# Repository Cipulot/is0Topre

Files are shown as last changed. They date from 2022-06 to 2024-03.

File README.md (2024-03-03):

# is0Topre

## Introduction

Topre version of the iconic is0 board.

This project is a continuation of my development of open source EC boards.

Below is the KLE of the supported layout:

is0Topre KLE

## Technical information

- Layout size: ISO enter
- Compatible switches: EC switches (Topre and NIZ)
- Microcontroller: Atmega32u4
- Connector: USB Type C
- Firmware compatibility: QMK (with VIA/VIAL support)
- Protection hardware:
  - Fused
  - ESD protection

**Addition: an empty spot for a 3.5x3.5mm SK series LED has been added to the back of the PCB, in case you want to manually add a bit of lighting.

## Renders and Prototypes

### is0Topre PCB

#### Render

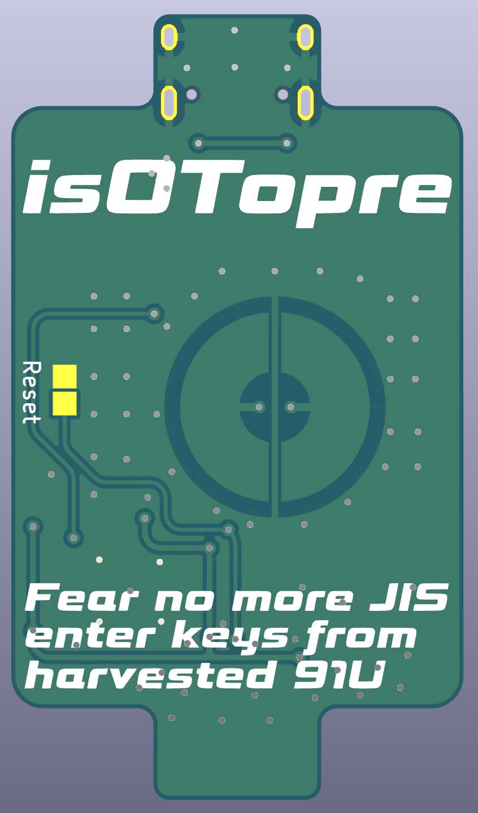
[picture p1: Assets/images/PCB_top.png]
is0Topre PCB Top Render


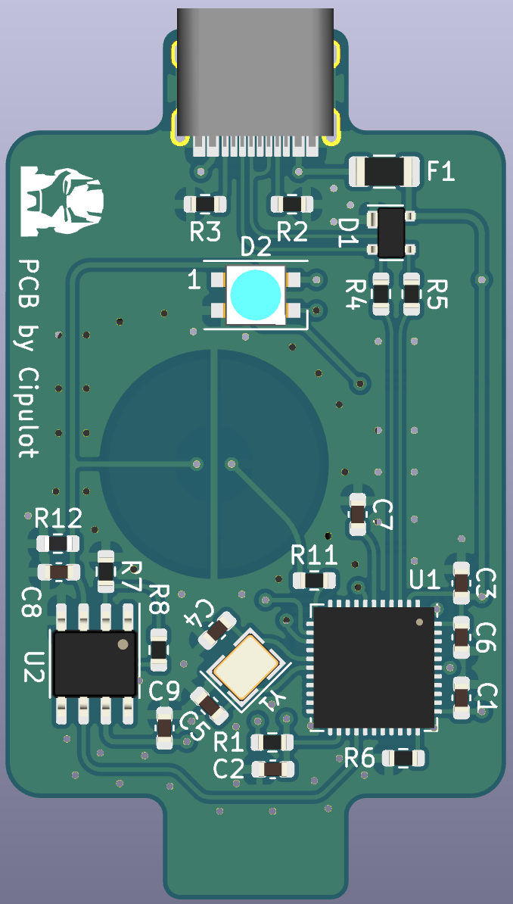
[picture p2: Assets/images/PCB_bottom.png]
is0Topre PCB Bottom Render


### Plate

#### Render

Topre housing compatible plate:

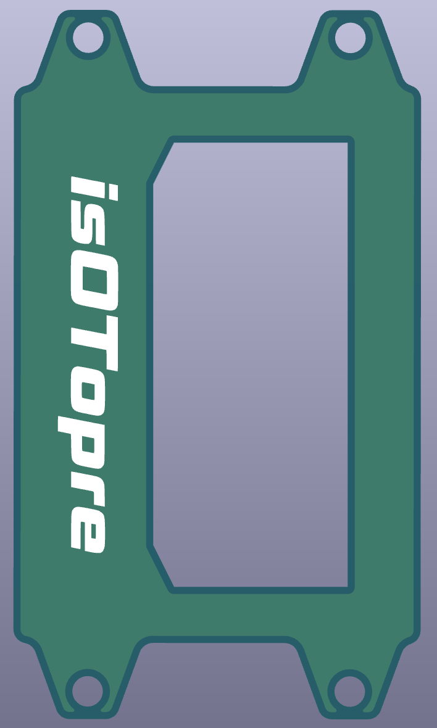
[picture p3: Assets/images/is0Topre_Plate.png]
is0Topre Plate Render


MX plate mounted stabilizer compatible plate:

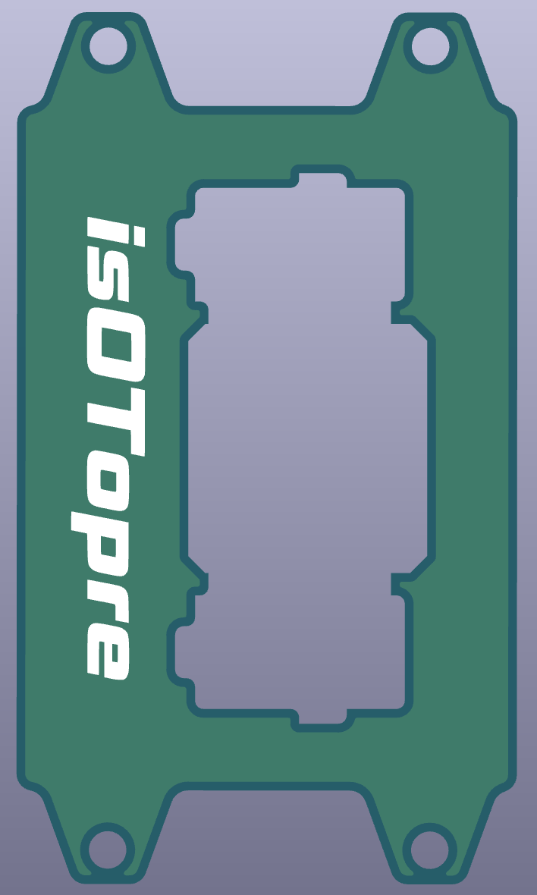
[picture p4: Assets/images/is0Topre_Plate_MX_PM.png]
is0Topre Plate MX Render


#### Prototype

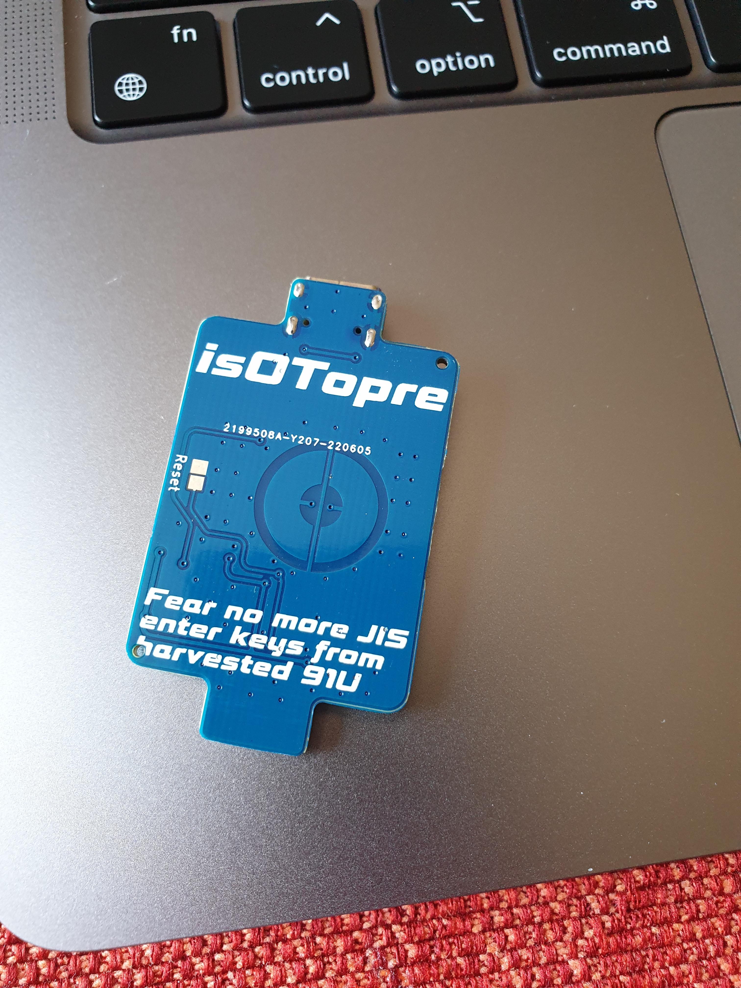
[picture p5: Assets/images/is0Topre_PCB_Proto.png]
is0Topre Proto


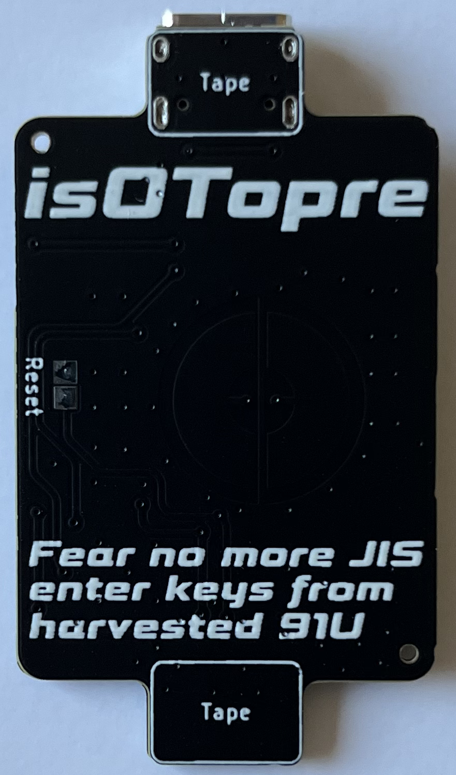
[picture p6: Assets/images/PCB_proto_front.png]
is0Topre Proto Front


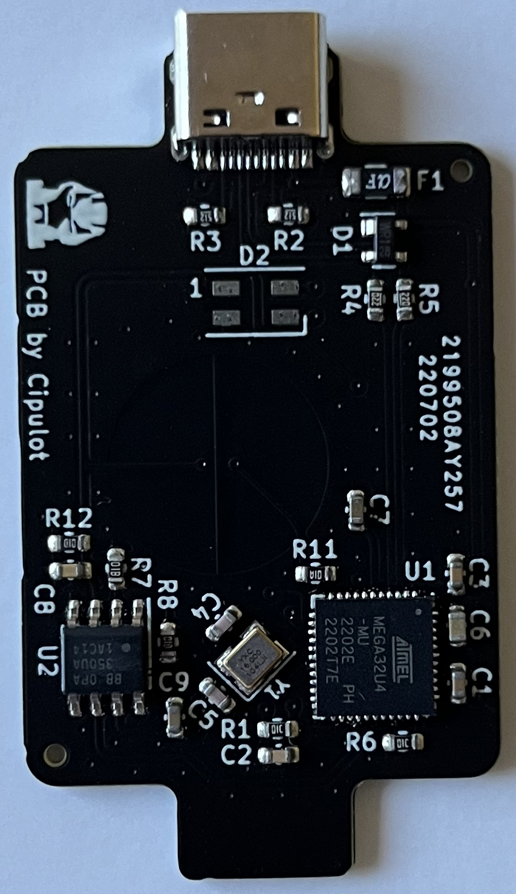
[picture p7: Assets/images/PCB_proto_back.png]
is0Topre Proto Back


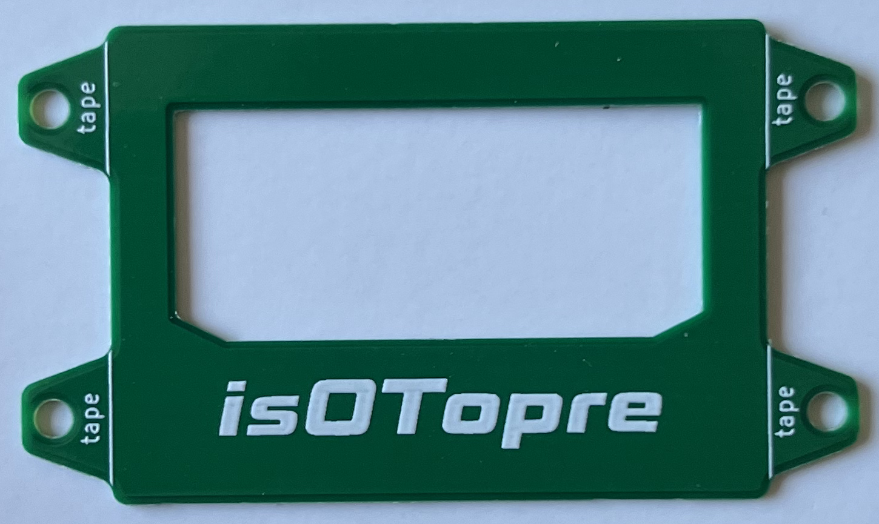
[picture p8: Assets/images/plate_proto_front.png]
is0Topre Plate Front


## WIP

Atmel MCU based firmware is validated, you can find the precompiled `.hex` (Vial compatible) and `.json` file for VIA in the firmware folder.

STM32 based MCU version is in development.

## Compatibility with is0 case

Given the difference in height and mounting system some modifications are needed.

At the time of ordering the PCBs be sure to use the following specs:

- 1.2mm thickness for the main PCB
- 0.6mm for the plates

In order to have the correct fit place in the marked spots adhesive tape, specifically:

- 2pcs, 0.4mm thick on the main PCB
- 4pcs, 0.1mm thick on the plates

These will ensure that all the tollerances are met and a secure fit is achieved.

## License

<br />This work is licensed under a <a rel="license" href="http://creativecommons.org/licenses/by-nc-sa/4.0/">Creative Commons Attribution-NonCommercial-ShareAlike 4.0 International License</a>.

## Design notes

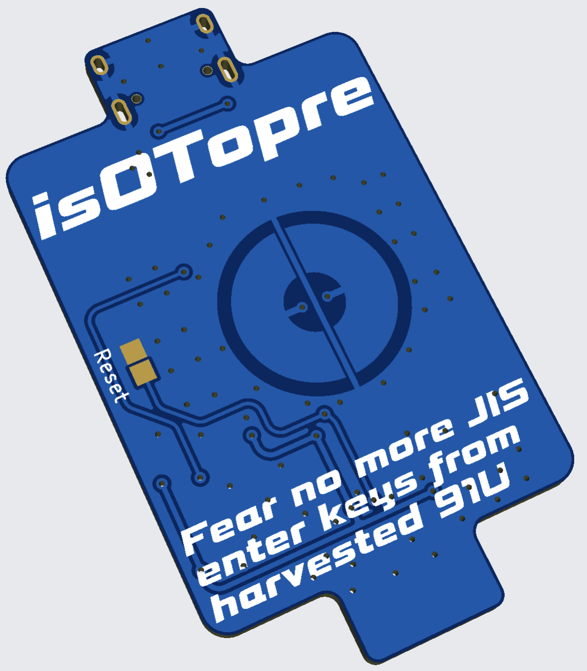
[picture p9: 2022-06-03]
Assets/images/Showcase_image.png

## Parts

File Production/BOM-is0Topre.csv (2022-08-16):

Comment | Designator | Footprint | LCSC
HRO-TYPE-C-31-M-12 | USB1 | HRO-TYPE-C-31-M-12-Assembly | C165948
1u | C7 | C_0603_1608Metric | C15849
PRTR5V0U2X | D1 | SOT-143 | C2827688
220p | C8 | C_0603_1608Metric | C1603
100k | R8,R12 | R_0603_1608Metric | C25803
10k | R6,R1 | R_0603_1608Metric | C25804
10u | C6 | C_0603_1608Metric | C96446
0.1u | C1,C9,C3,C2 | C_0603_1608Metric | C14663
22p | C5,C4 | C_0603_1608Metric | C1653
16MHz | Y1 | Crystal_SMD_3225-4pin_3.2x2.5mm | C13738
5.1k | R2,R3 | R_0603_1608Metric | C23186
22 | R5,R4 | R_0603_1608Metric | C23345
1k | R7 | R_0603_1608Metric | C21190
500mA | F1 | Fuse_1206_3216Metric | C70076
OPA350 | U2 | SOIC-8_3.9x4.9mm_P1.27mm | C13388
ATmega32U4-M | U1 | QFN-44-1EP_7x7mm_P0.5mm_EP5.2x5.2mm | C112161
100 | R11 | R_0603_1608Metric | C22775

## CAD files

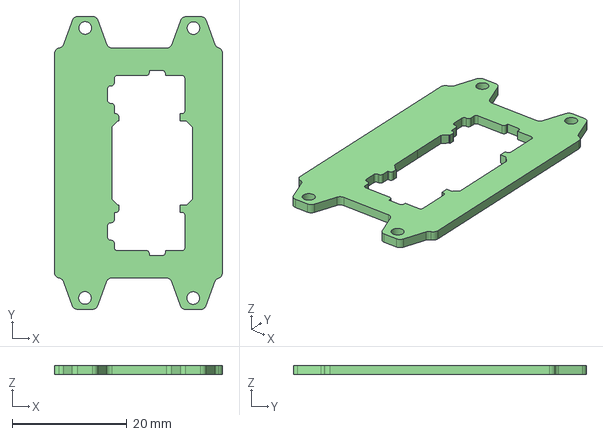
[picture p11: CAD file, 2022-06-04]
Assets/dev/is0Topre_Plate_MX_PM.STEP
29.3 x 51.1 x 1.60 mm

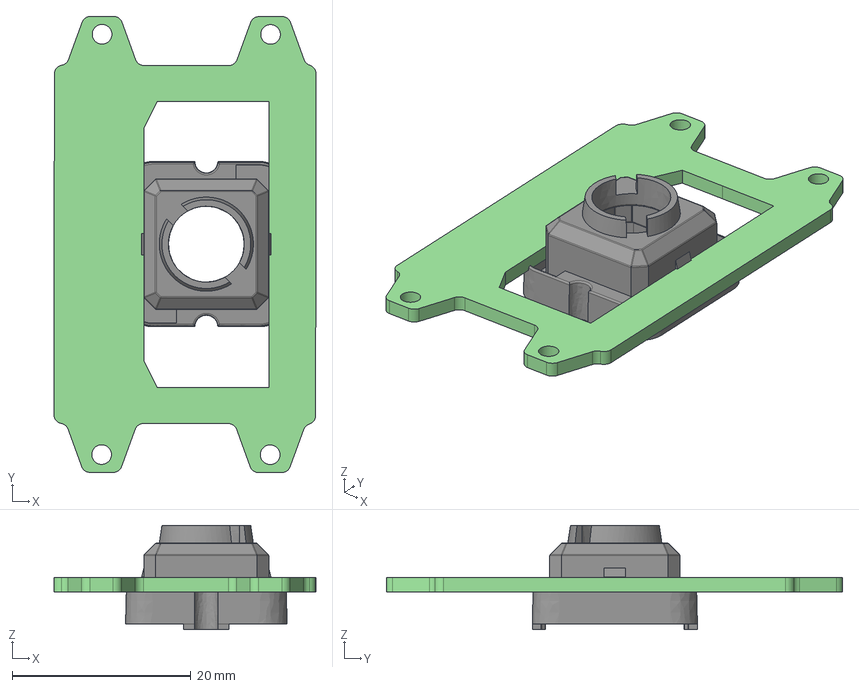
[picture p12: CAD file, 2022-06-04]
Assets/dev/is0Topre_Plate.STEP
29.3 x 51.1 x 11.7 mm
is0Topre_Plate PCB

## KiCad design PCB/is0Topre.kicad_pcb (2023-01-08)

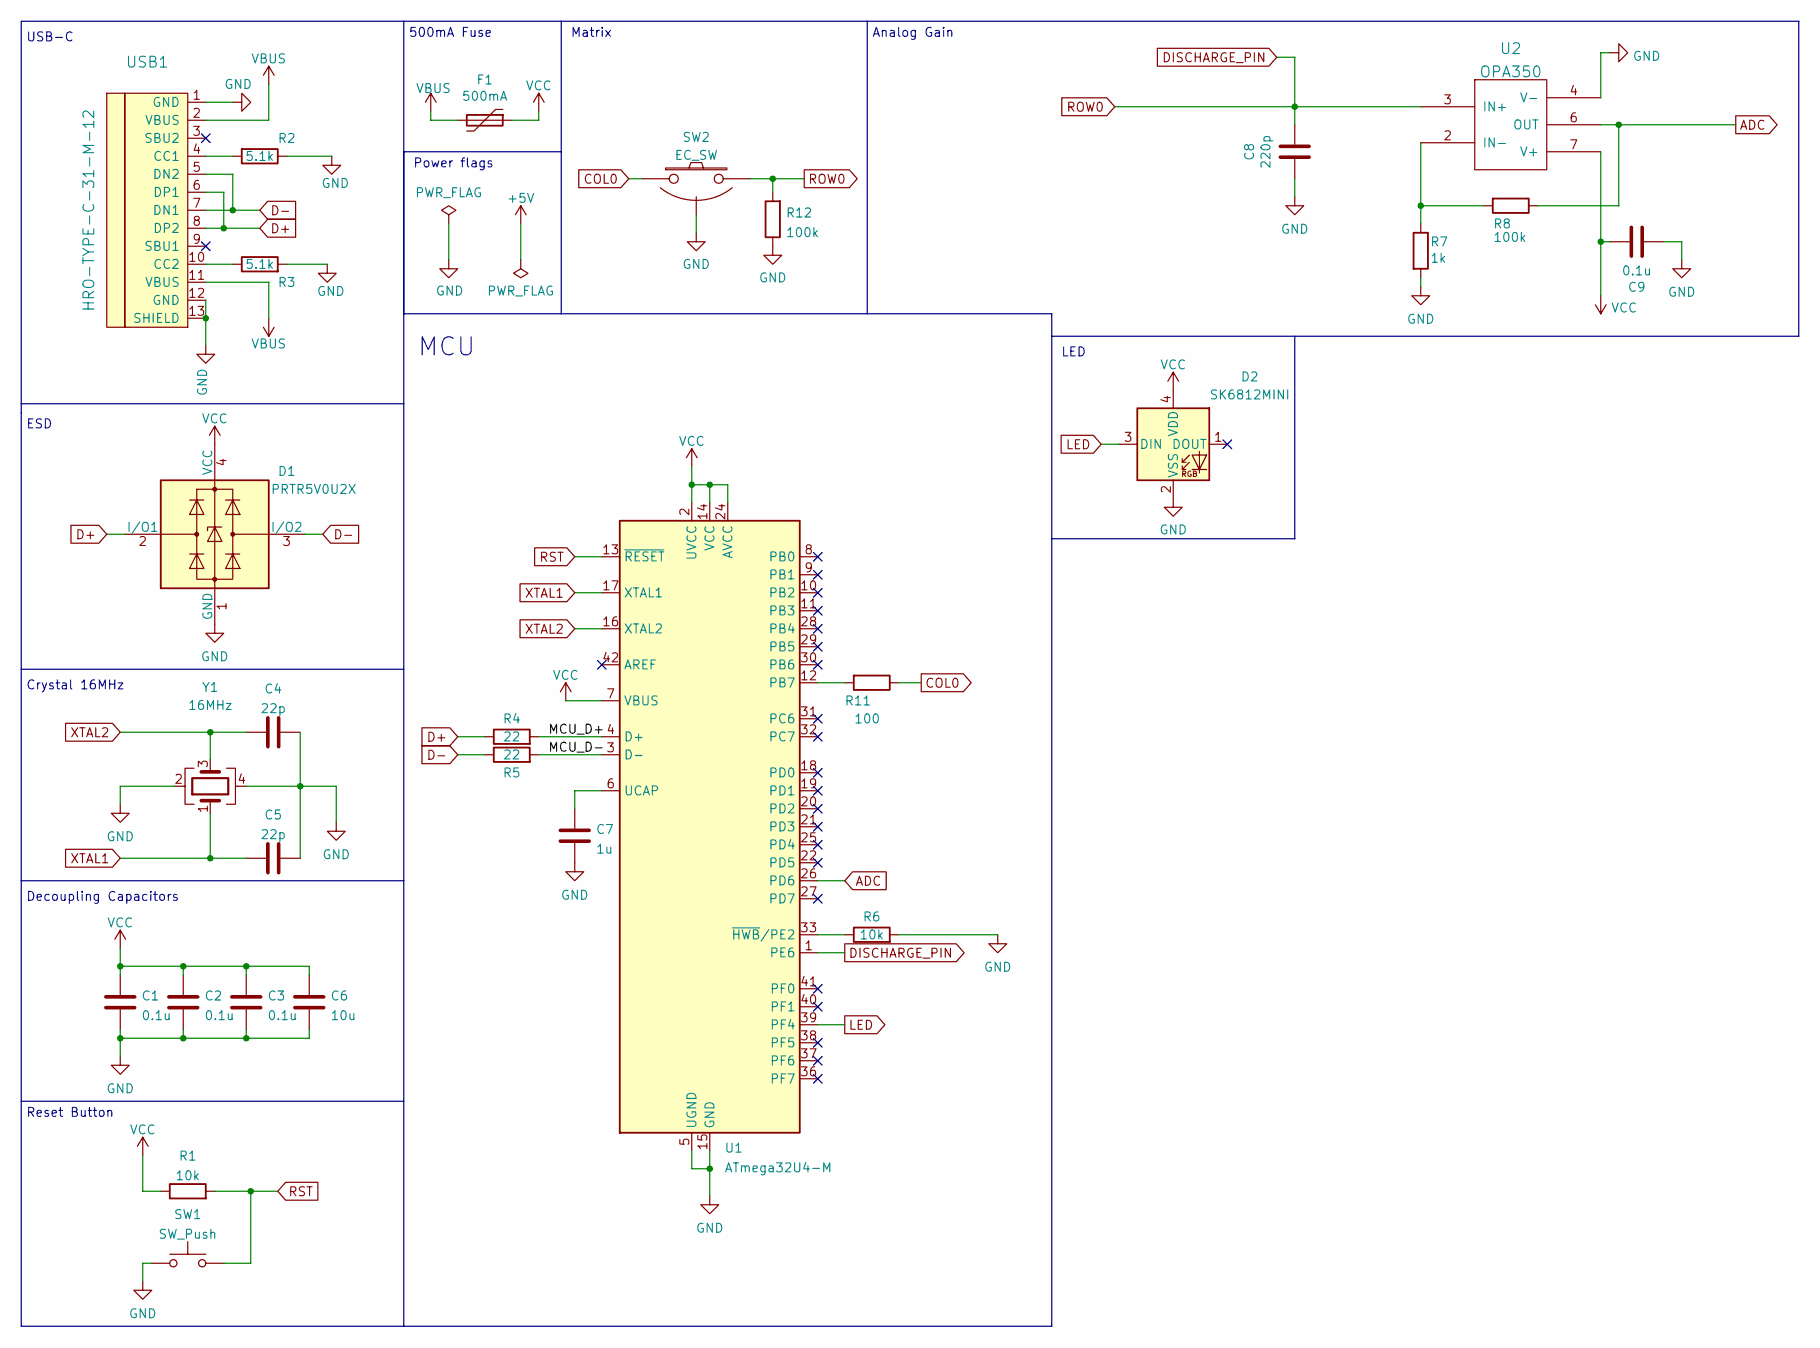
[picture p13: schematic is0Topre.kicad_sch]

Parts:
C1, C2, C3, C9: 0.1u; C_0603_1608Metric
C4, C5: 22p; C_0603_1608Metric
C6: 10u; C_0603_1608Metric
C7: 1u; C_0603_1608Metric
C8: 220p; C_0603_1608Metric
D1: PRTR5V0U2X; SOT-143
D2: SK6812MINI; LED_SK6812MINI_PLCC4_3.5x3.5mm_P1.75mm
F1: 500mA; Fuse_1206_3216Metric; LCSC Part # C70076
R1, R6: 10k; R_0603_1608Metric
R2, R3: 5.1k; R_0603_1608Metric
R4, R5: 22; R_0603_1608Metric
R7: 1k; R_0603_1608Metric
R8, R12: 100k; R_0603_1608Metric
R11: 100; R_0603_1608Metric
SW1: SW_Push; Jumper-UserFriendly-Small
SW2: EC_SW; ecs_pad_2U_no_ring
U1: ATmega32U4-M; QFN-44-1EP_7x7mm_P0.5mm_EP5.2x5.2mm; LCSC Part # C112161
U2: OPA350; SOIC-8_3.9x4.9mm_P1.27mm
USB1: HRO-TYPE-C-31-M-12; HRO-TYPE-C-31-M-12-Assembly
Y1: 16MHz; Crystal_SMD_3225-4pin_3.2x2.5mm; LCSC Part # C13738

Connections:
/MCU_D+: R4.2, U1.4 (D+)
/MCU_D-: R5.2, U1.3 (D-)
ADC: R8.1, U1.26 (PD6), U2.6 (OUT)
COL0: R11.1, SW2.1
D+: D1.2 (I/O1), R4.1, USB1.6 (DP1), USB1.8 (DP2)
D-: D1.3 (I/O2), R5.1, USB1.5 (DN2), USB1.7 (DN1)
DISCHARGE_PIN: C8.1, R12.2, SW2.2, U1.1 (PE6), U2.3 (IN+)
GND: C1.2, C2.2, C3.2, C4.1, C5.1, C6.2, C7.2, C8.2, C9.1, D1.1 (GND), D2.2 (VSS), R2.1, R3.2, R6.2, R7.2, R12.1, SW1.1, SW2.3 (SG), U1.5 (UGND), U1.15 (GND), U1.23 (GND), U1.35 (GND), U1.43 (GND), U1.45 (GND), U2.4 (V-), USB1.1 (GND), USB1.12 (GND), USB1.13 (SHIELD), Y1.2, Y1.4
LED: D2.3 (DIN), U1.39 (PF4)
unnamed: C7.1, U1.6 (UCAP)
unnamed: R2.2, USB1.4 (CC1)
unnamed: R3.1, USB1.10 (CC2)
unnamed: R6.1, U1.33 (~HWB/PE2)
unnamed: R7.1, R8.2, U2.2 (IN-)
unnamed: R11.2, U1.12 (PB7)
RST: R1.2, SW1.2, U1.13 (~RESET)
VBUS: F1.2, USB1.2 (VBUS), USB1.11 (VBUS)
VCC: C1.1, C2.1, C3.1, C6.1, C9.2, D1.4 (VCC), D2.4 (VDD), F1.1, R1.1, U1.2 (UVCC), U1.7 (VBUS), U1.14 (VCC), U1.24 (AVCC), U1.34 (VCC), U1.44 (AVCC), U2.7 (V+)
XTAL1: C5.2, U1.17 (XTAL1), Y1.1
XTAL2: C4.2, U1.16 (XTAL2), Y1.3

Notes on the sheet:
USB-C
Analog Gain
LED
500mA Fuse
MCU
Decoupling Capacitors
Power flags
Matrix
Crystal 16MHz
ESD
Reset Button

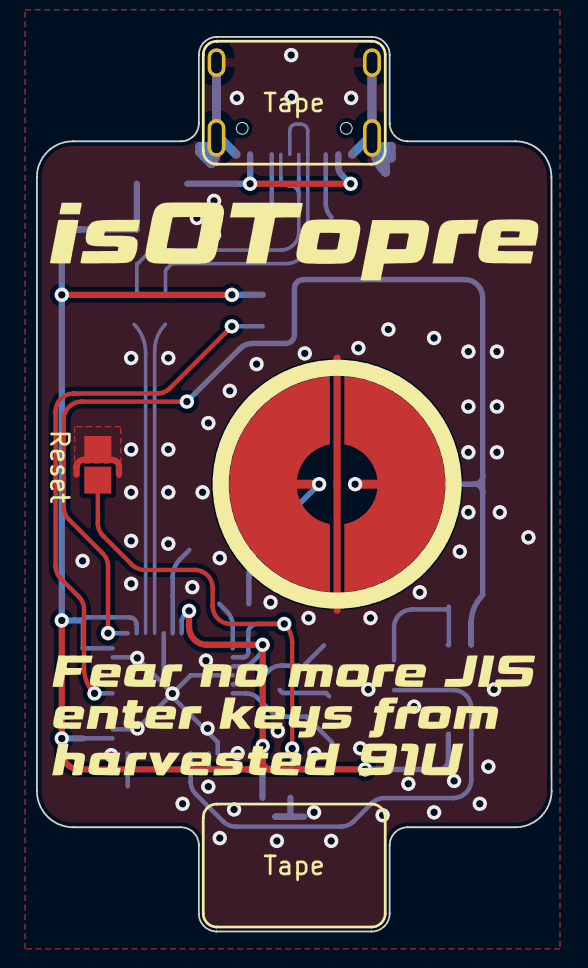
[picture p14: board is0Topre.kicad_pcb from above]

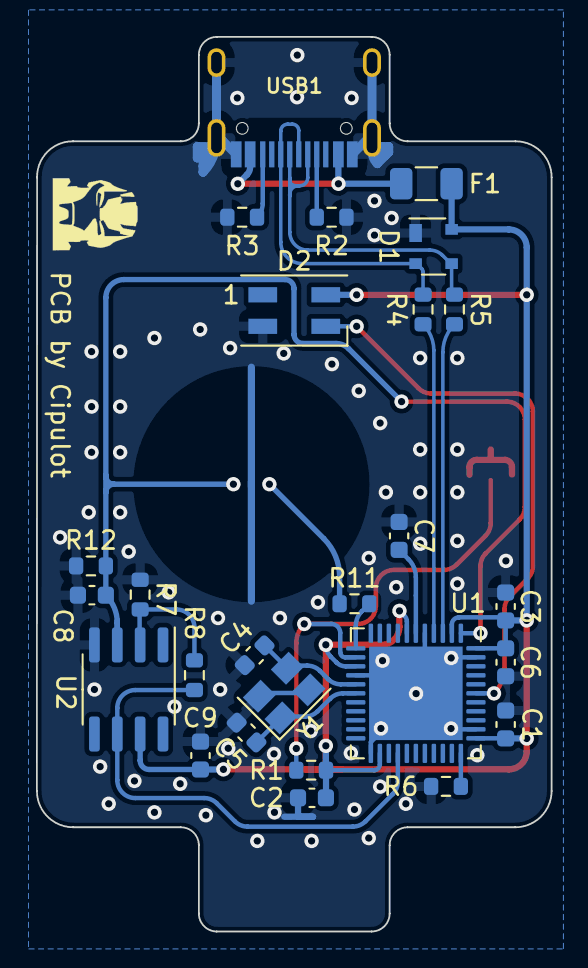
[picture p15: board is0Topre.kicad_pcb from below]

Board: 2 copper layers, 28.6 x 49.7 mm, 28 parts (26 on the bottom side), 20 nets.

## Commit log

2022-06-03 Assets init
    [WT1-A_v1_1_v1.step, iSO_render_1.step, is0_outline.dxf]
2022-06-03 PCB project init
    [is0Topre.kicad_pcb, is0Topre.kicad_sch]
2022-06-03 First production files
    [BOM-is0Topre.csv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]
2022-06-04 Added plate files
    Files for Topre 2u sw and MX compatible stabs through plate mounted stabilizer.
    [is0Topre_Plate.dxf, is0Topre_Plate.kicad_pcb, is0Topre_Plate_MX_PM.kicad_pcb]
2022-06-04 Repo cleanup and additions
    [WT1-A_v1_1_v1.step, iSO_render_1.step, is0Topre_Plate.STEP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]
2022-06-06 Fix for resistor missing
    [BOM-is0Topre.csv, is0Topre.kicad_pcb, is0Topre.kicad_sch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]
2022-06-06 Updated render
    Render picture updated after change in PCB to fix resistor error.
2022-06-14 Update of circuit after PCB testing
    [BOM-is0Topre.csv, is0Topre.kicad_pcb, is0Topre.kicad_sch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]
2022-06-14 Update firmware and PCB files for LED support
    [BOM-is0Topre.csv, is0Topre.kicad_pcb]
2022-06-16 Updated pic and production to add logo
    [is0Topre.kicad_pcb]
2022-06-20 Update to add tape silkscreen
    [is0Topre.kicad_pcb, is0Topre_Plate.kicad_pcb, is0Topre_Plate_MX_PM.kicad_pcb]
2022-06-30 Update of BOM
    [BOM-is0Topre.csv]
2022-07-25 Update BOM-is0Topre.csv
    Change to 8MHz resonator
    [BOM-is0Topre.csv]
2022-07-25 Update POS-is0Topre.csv
    Change label to 8MHz
    [POS-is0Topre.csv]
2022-07-26 Revert "Update BOM-is0Topre.csv"
    This reverts commit b2ed54e3cb7e963670c5bac463af23f9a7a3efb1.
    [BOM-is0Topre.csv]
2022-07-26 Revert "Update POS-is0Topre.csv"
    This reverts commit f306154f2dc278414dedb12f148aa883d78f8acf.
    [POS-is0Topre.csv]
2022-08-16 Update BOM-is0Topre.csv
    Moved from MUR to MU bc usually cheaper option at JLC.
    [BOM-is0Topre.csv]
2023-01-08 Update for 3d models
    [is0Topre.kicad_pcb, is0Topre.kicad_sch]
2023-03-26 Update README.md
    fixed plate picture link
